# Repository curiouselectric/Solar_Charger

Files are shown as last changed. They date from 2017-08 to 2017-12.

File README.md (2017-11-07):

# Solar_Charger
A DIY Solar Charger for 18650 Lithium Ion cells.

Get off-grid, power your remote project and learn about solar power with this DIY solar charger kit.

This is a relatively simple open-source kit, sold at www.curiouselectric.co.uk and on Tindie: https://www.tindie.com/products/reinnovation/solar-matic/, which includes two 1Wp solar PV panels and all the parts required to recharge standard 18650 lithium ion cells.

The charger IC is the [BQ24210 from Texas Instruments](http://www.ti.com/lit/ds/symlink/bq24210.pdf). This is an amazing single-cell Lithium Ion battery charge IC with up to 800mA current rating. It is designed to maximise the output from a solar PV cell into the battery. This is a very small surface mount component in a WSON-10 package, so we have soldered this to the PCB for you.

The kit is uses a DC-DC converter which ensures a regulated 5V output, either for a USB connector output or for screw terminals. The DC-DC converter is controlled via a switch on the side of the PCB.

The unit comes with a simple laser-cut enclosure so it can be placed on a window-sill or hung somewhere.

This is a reasonably simple kit which requires some soldering and a few fiddly connections.

*Note: Depending upon the capacity of the 18650 cell, in the UK the battery will fully recharge in around 3-5 days during an average summers day. This totally depends upon the solar resource available.*

*Note: The enclosure is NOT waterproof or for outdoor use.*

This repository is for all the design files for this project.
This includes:

* PCB design (KiCAD files)
* Enclosure Design (.dxf designs)
* Instructions (open-office and .pdf)

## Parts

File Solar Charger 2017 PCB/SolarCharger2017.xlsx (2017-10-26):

Reference | Value | Footprint | Datasheet | Description | Supplier 1 | Supplier 1 Part No | Supplier 1 Cost | Manufacturer | Manufacturer Part No
BT1 | 18650 LiIon Cell | REInnovationFootprint:TH_LiIon_Holder |  | 18650 PCB mount holder | eBay | http://www.ebay.co.uk/itm/122466718109 | 0.5
C1 | 1uF | matts_components:C1V7_lg_pad_lg_hole |  |  |  |  | 0.1
C2 | 1uF | matts_components:C1V7_lg_pad_lg_hole |  |  |  |  | 0.1
D2 | CHG | REInnovationFootprint:TH_LED-5MM_larg_pad |  |  |  |  | 0.05
D3 | PG | REInnovationFootprint:TH_LED-5MM_larg_pad |  |  |  |  | 0.05
DCDC1 | DC-DC | REInnovationFootprint:TH_DCDC_Converter_USB |  |  | Aliexpress |  | 1.5
DCDC2 | DC-DC | REInnovationFootprint:TH_DCDC_Converter_NoUSB |  |  | Aliexpress |  | 1
LG1 | LOGO1 | CuriousElectric3:CEC_Globe_10mm_FCU
LG2 | LOGO2 | CuriousElectric3:TCEC_Words_13mm
P1 | 5V OUT | REInnovationFootprint:SIL-2_screw_terminal |  | screw terminal |  |  | 0.2
P2 | LiIon Cell V | REInnovationFootprint:SIL_2_screw_+_JST_2mm
P3 | PV IN 1 | REInnovationFootprint:SIL_2_screw_+_JST_2mm
P4 | PV IN 2 | REInnovationFootprint:SIL_2_screw_+_JST_2mm
P5 | LiIon Cell V | REInnovationFootprint:SIL_2_screw_+_JST_2mm
P6 | 5V OUT | REInnovationFootprint:SIL-2_screw_terminal
PCB1 | PCB | REInnovationFootprint:PCB_65x90mm |  |  | Elecrow |  | 3
R1 | 1k | REInnovationFootprint:TH_Resistor_1 |  |  |  |  | 0.01
R2 | 100k | REInnovationFootprint:TH_Resistor_1 |  |  |  |  | 0.01
R3 | 2.2k | REInnovationFootprint:TH_Resistor_1 |  |  |  |  | 0.01
R4 | 2.2k | REInnovationFootprint:TH_Resistor_1 |  |  |  |  | 0.01
SC1 | PV <2W 5.5V | REInnovationFootprint:PV_130mmx65mm_NoOutline |  | 1-2W solar PV module | Aliexpress |  | 2.5
SW1 | 5V ON | REInnovationFootprint:SW_SPDT_R_Angle_ALIEX |  |  | Aliexpress |  | 0.2
U1 | BQ24210 | REInnovationFootprint:SM_WSON-10-2x3 | http://www.ti.com/lit/ds/symlink/bq24210.pdf | LiIon Charger 800mA PV Input | RS | 742-2836 | 2.88 | Texas Instruments | BQ24210
Hardware | M3 screws etc. |  |  |  |  |  | 0.6
Enclsoure | Plate |  |  |  |  |  | 2.15
 |  |  |  |  |  | TOTAL COST: | 14.87
 |  |  |  |  |  | Kit cost | £25.00

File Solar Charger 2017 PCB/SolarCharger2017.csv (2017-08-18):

Reference | Value | Footprint | Datasheet | Description | Supplier 1 | Supplier 1 Part No | Supplier 1 Cost | Manufacturer | Manufacturer Part No
BT1 | 18650 LiIon Cell | REInnovationFootprint:TH_LiIon_Holder |  | 18650 PCB mount holder | eBay | http://www.ebay.co.uk/itm/122466718109 | 0.50
SC1 | PV <2W 5.5V | REInnovationFootprint:PV_130mmx65mm_NoOutline |  | 1-2W solar PV module | Aliexpress |  | 2.5
DCDC1 | DC-DC | REInnovationFootprint:TH_DCDC_Converter_USB |  |  | Aliexpress |  | 1.5
U1 | BQ24210 | REInnovationFootprint:SM_WSON-10-2x3 | http://www.ti.com/lit/ds/symlink/bq24210.pdf | LiIon Charger 800mA PV Input | RS | 742-2836 | 2.88 | Texas Instruments | BQ24210
D2 | CHG | REInnovationFootprint:TH_LED-5MM_larg_pad |  |  |  |  | 0.05
D3 | PG | REInnovationFootprint:TH_LED-5MM_larg_pad |  |  |  |  | 0.05
R3 | 2.2k | REInnovationFootprint:TH_Resistor_1 |  |  |  |  | 0.01
R4 | 2.2k | REInnovationFootprint:TH_Resistor_1 |  |  |  |  | 0.01
C1 | 1uF | matts_components:C1V7_lg_pad_lg_hole |  |  |  |  | 0.1
C2 | 1uF | matts_components:C1V7_lg_pad_lg_hole |  |  |  |  | 0.10
R1 | 1k | REInnovationFootprint:TH_Resistor_1 |  |  |  |  | 0.01
P2 | LiIon Cell V | REInnovationFootprint:SIL_2_screw_+_JST_2mm
SW1 | 5V ON | REInnovationFootprint:SW_SPDT_R_Angle_ALIEX |  |  | Aliexpress |  | 0.2
R2 | 100k | REInnovationFootprint:TH_Resistor_1 |  |  |  |  | 0.01
LG1 | LOGO1 | CuriousElectric3:CEC_Globe_10mm_FCU
LG2 | LOGO2 | CuriousElectric3:TCEC_Words_13mm
P1 | 5V OUT | REInnovationFootprint:SIL-2_screw_terminal
P3 | PV IN 1 | REInnovationFootprint:SIL_2_screw_+_JST_2mm
P4 | PV IN 2 | REInnovationFootprint:SIL_2_screw_+_JST_2mm
PCB1 | PCB | REInnovationFootprint:PCB_65x90mm
DCDC2 | DC-DC | REInnovationFootprint:TH_DCDC_Converter_NoUSB |  |  | Aliexpress |  | 1
P6 | 5V OUT | REInnovationFootprint:SIL-2_screw_terminal
P5 | LiIon Cell V | REInnovationFootprint:SIL_2_screw_+_JST_2mm

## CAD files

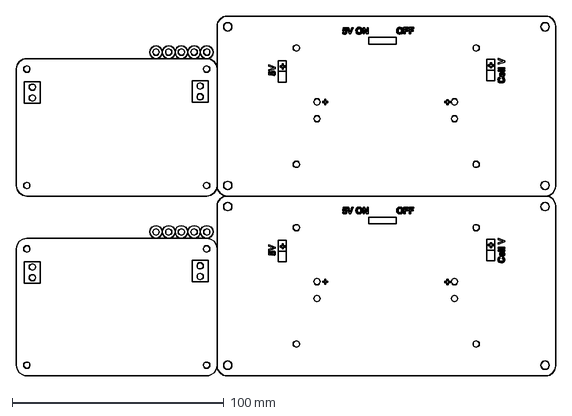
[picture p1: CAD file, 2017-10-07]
Solar Charger Hardware/Solar Charger Enclosure.dxf
254.9 x 170.0 mm

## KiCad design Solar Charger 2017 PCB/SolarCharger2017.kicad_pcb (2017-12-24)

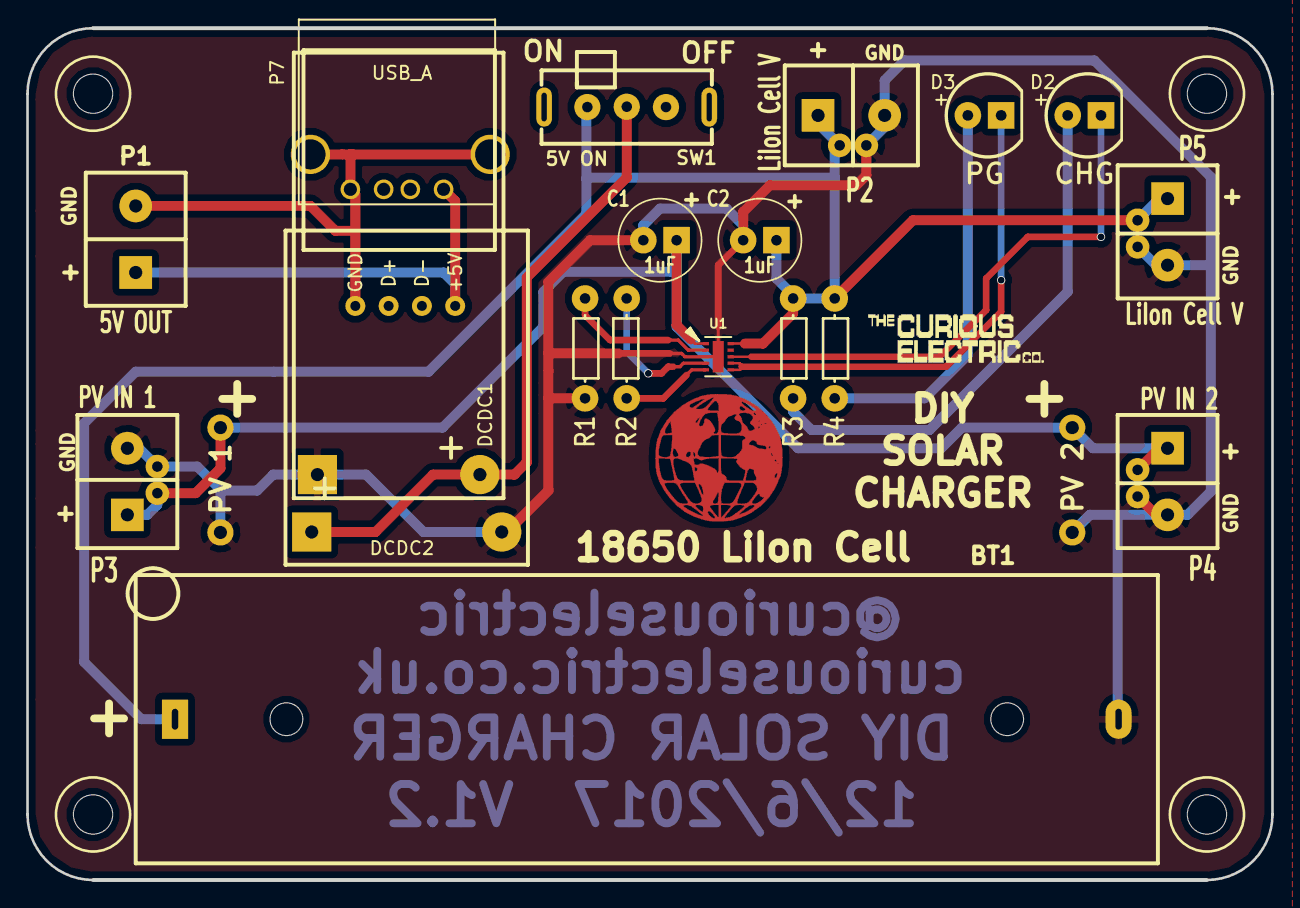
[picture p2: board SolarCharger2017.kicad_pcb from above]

Board: 2 copper layers, 95.0 x 65.0 mm, 23 parts (0 on the bottom side), 13 nets.

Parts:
BT1: 18650 LiIon Cell; TH_LiIon_Holder
C1, C2: 1uF; C1V7_lg_pad_lg_hole
D2: CHG; TH_LED-5MM_larg_pad
D3: PG; TH_LED-5MM_larg_pad
DCDC1: DC-DC; TH_DCDC_Converter_USB
DCDC2: DC-DC; TH_DCDC_Converter_NoUSB
LG1: LOGO1; CEC_Globe_10mm_FCU
LG2: LOGO2; TCEC_Words_13mm
P1: 5V OUT; SIL-2_screw_terminal
P2, P5: LiIon Cell V; SIL_2_screw_+_JST_2mm
P3: PV IN 1; SIL_2_screw_+_JST_2mm
P4: PV IN 2; SIL_2_screw_+_JST_2mm
P7: USB_A
PCB1: PCB; PCB_65x90mm
R1: 1k; TH_Resistor_1
R2: 100k; TH_Resistor_1
R3, R4: 2.2k; TH_Resistor_1
SC1: PV <2W 5.5V; PV_130mmx65mm_NoOutline
SW1: 5V ON; SW_SPDT_R_Angle_ALIEX
U1: BQ24210; SM_WSON-10-2x3

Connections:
GND: BT1.2, C1.2, C2.2, DCDC1.1, DCDC2.1, P2.2, P3.2, P4.2, P5.2, R1.2, SC1.2, U1.3, U1.PAD
unnamed: C1.1, P3.1, P4.1, SC1.1, U1.1
unnamed: D2.1, U1.8
unnamed: D2.2, R3.2
unnamed: D3.1, U1.6, U1.7
unnamed: D3.2, R4.2
unnamed: DCDC1.2, DCDC2.2, SW1.2
unnamed: DCDC2.3, P1.1, P7.1
unnamed: DCDC2.4, P1.2, P7.4, P7.5
unnamed: R1.1, U1.2
unnamed: R2.1, U1.5
unnamed: R2.2, U1.4
VCC: BT1.1, C2.1, P2.1, P5.1, R3.1, R4.1, SW1.1, U1.10

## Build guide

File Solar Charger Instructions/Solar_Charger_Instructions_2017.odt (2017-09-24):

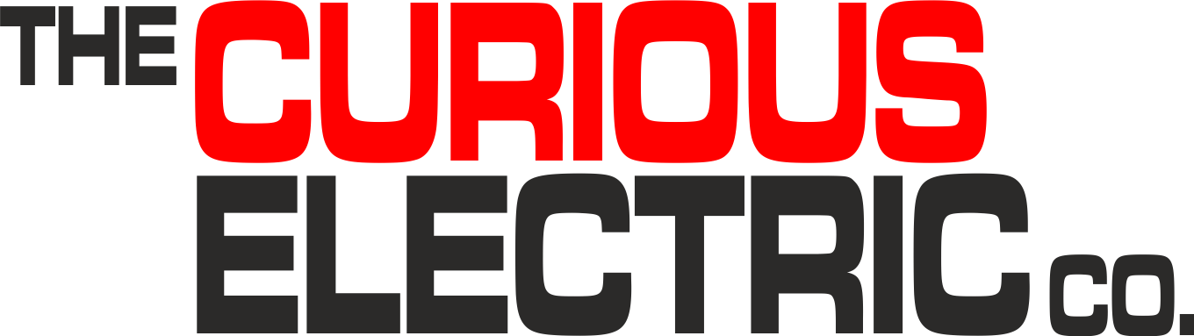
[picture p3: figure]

| Solar Charger Kit Instructions

Date: | 15/09/17 | Version: | 1.0 | By: | Matt Little

This is a DIY solar LiIon charger unit.

It is designed to run small electronics projects (such as data-loggers and environmental monitoring units) in places where there is no supply of electricity. I designed it originally to run a small weather station which monitored and wirelessly sent back data to a base station.

It uses the Texas Instruments BQ24210 (http://www.ti.com/product/BQ24210).

This is a 800mA single-input, single cell Lithium Ion battery charger IC. The datasheet is available here:http://www.ti.com/lit/ds/slusa76b/slusa76b.pdf

This IC is pre-soldered, as it is a very small SMD. All the other parts are through-hole and can be soldered by hand.

The kit uses 2 x 1W 5V solar PV cells (connected in parallel).

This IC is used to recharge a single 18650 LiIon cell, which are widely available in a range of capacities.

The output can be used directly, as the voltage of the LiIon cell (around 3.7-4.4V DC). This can be used on micro-controller projects, such as data-loggers and weather stations which might need a local source of reliable, off-grid power.

There is also a DC/DC converter unit to provide a 5V output. The 5V output is switched. The 5V output can be used to power USB devices or your microcontroller projects.

This is a reasonably simple kit which requires some soldering.

It should take 1-2 hours to build.

Not suitable for under 12 years old.

# Parts included:

| | | Laser-cut Enclosure | | | 3 x AA rechargeable batteries
1W Solar PV Modules
| | | | | | | | Battery Holder
DC-DC Converter
| | | | | | | | 7 x M3 Hex spacers
PCB | | | | | | | | 7 x M3 6mm 7 x M3 8mm
| | | | | | | | Sticky Pads
Wire
| | Diode 1N4001 | | | | Switch + 2 x M2.5 screws

# Enclosure Parts:

Top 1 | | Front
Top 2
Top 3 | | Back
Bottom 1
Bottom 1
Bottom 1 | | Switch Holder

# PCB Parts List:

Ref | Item | Quantity | Ref | Item | Quantity
BT1 | 18650 Cell Holder | 1 | R1 | 1k resistor | 1
Battery | 18650 Cell | *Not included | R2 | 100k Resistor | 1
C1, C2 | 1uF Capacitor | 2 | R3, R4 | 2k2 Resistor | 2
D2, D3 | LED | 2 | PV1, PV2 | 1W 5V PV module | 2
DCDC | DC-DC boost converter | 1 | SW1 | Switch | 1
P1, P2, P3, P4, P5, P6 | 2 way Screw Terminal | 6 | U1 | BQ24210 | 1
PCB1 | Circuit Board | 1

*Note: We do NOT supply the 18650 size Lithium Ion cell. This is due to shipping restrictions. These cells are easily available locally.

# Hardware Parts List:

Ref | Item | Quantity | Ref | Item | Quantity

# Tools required:

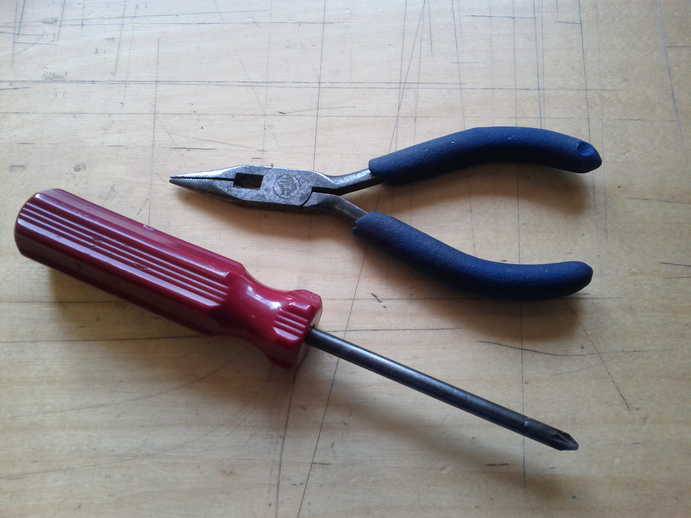
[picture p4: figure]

Posi-drive Screwdriver
| | Long-nosed Pliers
| | Soldering Iron
| | Solder
| | Side cutters
| | (not shown)

Instructions:

Step: 1

Step: 2

Step: 3

Step: 4

Step: 16 | Build is finished!

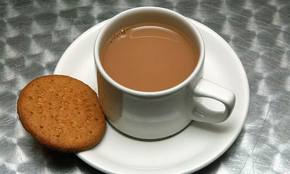
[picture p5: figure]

| | Have a nice cup of tea.

Note: The weather and available sunlight is variable, so there are no definite rules about recharging times.

If outside on an average UK summers day the batteries will be fully charged in one day.

If outside on an average UK winters day then the batteries will be fully charged in 2-3 days.

If used behind a window, the glass will affect the available sunlight and increase the recharge times by a factor or around 50%.

# Contact details:

This kit has been designed and produced by:

The Curious Electric Company

hello@curiouselectric.co.uk

www.curiouselectric.co.uk

Hopkinson Gallery, 21 Station Street, Nottingham, NG2 3AJ

We would like you to be happy with this kit. If you are not happy for any reason then please contact us and we will help to sort it out.

Please email hello@curiouselectric.co.uk with any questions or comments.

Please tweet us at @curiouselectric

If any parts are missing from your kit then please email hello@curiouselectric.co.uk with details, including where the kit was purchased.

More technical information can be found via www.curiouselectric.co.uk

# Circuit Schematic:

# Useful Notes:

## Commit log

2017-06-12 Initial comit
    [SolarCharger2017.kicad_pcb, SolarCharger2017.sch]
2017-06-12 Update of PCB
    [SolarCharger2017-B.Cu.gbr, SolarCharger2017-B.Mask.gbr, SolarCharger2017-B.SilkS.gbr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]
2017-08-18 Changes to PCB
    DC-DC converter correct. Moved silkscreen. Sorted costs
    [SolarCharger2017.csv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]
2017-08-18 Added gerbers
    [SolarCharger2017-B.Cu.gbr, SolarCharger2017-B.Mask.gbr, SolarCharger2017-B.SilkS.gbr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]
2017-08-18 Update of Gerber
    [SolarCharger2017-B.Cu.gbr, SolarCharger2017-B.Mask.gbr, SolarCharger2017-B.SilkS.gbr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]
2017-08-18 Slight update of schematic
    [SolarCharger2017.sch]
2017-09-15 Updated PCB
    [SolarCharger2017-B.Cu.gbr, SolarCharger2017-B.Mask.gbr, SolarCharger2017-B.SilkS.gbr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]
2017-09-24 Updated instructions and parts list
    [SolarCharger2017.xlsx]
2017-10-07 Updated enclosure
    [Solar Charger Enclosure.dxf]
2017-10-26 Added instructions
    [SolarCharger2017.sch, SolarCharger2017.xlsx]
2017-11-17 Update of instructions
    [SolarCharger2017.kicad_pcb, SolarCharger2017.sch]
2017-12-24 Update of PCB with USB output
    Slight change to the USB output.
    [SolarCharger2017-B.Cu.gbr, SolarCharger2017-B.Mask.gbr, SolarCharger2017-B.SilkS.gbr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]
